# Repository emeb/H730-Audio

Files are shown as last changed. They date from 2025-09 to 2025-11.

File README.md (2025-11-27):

# H730-Audio

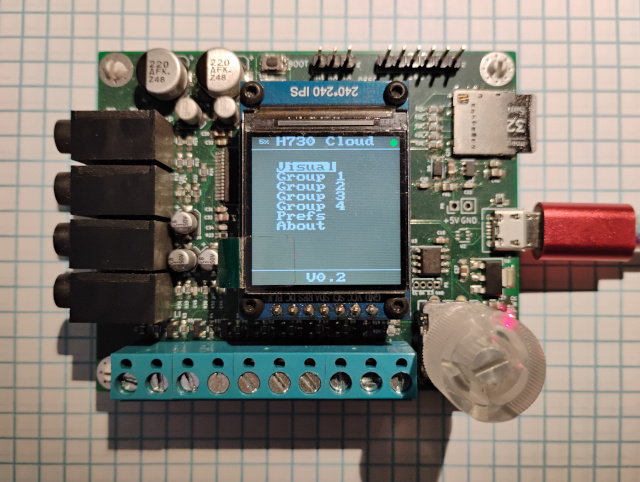
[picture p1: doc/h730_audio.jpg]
A small audio DSP board with GPIO, GUI and SD card.

## Abstract

A few years ago I was approached by my friend and colleague [Robert Rich](https://robertrich.com/) to help with a fascinating audio project that would be used to create immersive audio installations. He needed a device that would process sound in different ways - sometimes responding to sound, sometimes responding to environmental conditions. We kicked the ideas around for a while and tried various off-the-shelf solutions (Raspberry Pi, etc) but nothing was quite right so I ended up designing the H730 Audio board from scratch specifically for his requirements. The board needed audio input and output, storage, on-site configurability and the ability to use light sensors and this is what we ended up with:

- STM32H730 microcontroller - this is a compact, inexpensive and powerful device with plenty of I/O and on-chip resources that make for a capable "blank slate" on which to implement any DSP we might come up with

- WM8731 codec - I had a good stock of these in my inventory and I was very familiar with it. The device is EOL now and difficult to get, but in 2020 it was still a viable option. Today I'd probably use something like the Nuvoton NAU88C22 for equivalent features and performance.

- Micro SD-card slot - this is for storing long audio files of ambient recording and playback.

- 8 channel voltage-protected GPIO on a terminal block - for connecting sensors in environmental response installations. Specifically we used surplus solar panels to detect light changes throughout the day in order to modulate audio pitch and timbre.

- Micro USB - primarily used for 5V power, but also for USB DFU software updates.

- 240x240 IPS LCD - for user interface.

- Rotary encoder with pushbutton - for user interface.

- Quad SPI footprint for PSRAM or Flash memory - for audio sample storage or delay memory.

- 32kB I2C EEPROM - for user setting storage.

- Miscellaneous I/O headers for debug/development and "future expansion"

## Hardware

The design was created in an older version of Kicad and five boards were hand assembled - four went to Robert and several have been used in museum installations along with supporting hardware hand-built by Robert. The remaining board is in my collection. Design materials can be found in the [Hardware](./Hardware) directory.

## Firmware

Applications for this board were created in C using the STM32 HAL and ARM CMSIS libraries. Two audio installations are supported - a light-sensitive cloud generator and a day-long audio environment delay/feedback system. The source code for these applications is not provided at this time as they are proprietary, but basic hardware drivers are available in the [Firmware](./Firmware) directory.

## Documentation

The full users guide for the board with info on the I/O ports and use of the audio applications is here: [User Guide](./doc/h730_audio_info.pdf)

The board schematic is here: [Schematic](./doc/h730_audio_sch.pdf)

## Going Further

 Robert has a nice write-up on the system this board was used in over on his site that includes photos and videos:

[Sound Sculpture](https://robertrich.com/graphic-art/sound-sculpture/)

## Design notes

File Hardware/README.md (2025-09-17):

## H730 Audio - Hardware

This directory contains the Kicad 9.x design data for the H730 Audio board.
Note this was originally created in an earlier version of Kicad and although
was functional and correct in that environment, it has been automatically
upgraded to 9.x so there may be errors. Please use caution, run all applicable
DRC checks, etc before attempting to fab this design.

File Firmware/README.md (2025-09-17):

## H730 Firmware

This directory contains the firmware source code for the H730 Audio board, including the STM32 HAL and ARM CMSIS libraries that were used to build it. There is source code for basic functionality but the cloud and delay applications are withheld at this time.

The two applications are:

- blinky - basic initial test of the blinking LED on the board.

- main - a boilerplate / template for creating other applications that intializes all the on-board resources and creates a basic audio I/O stream.

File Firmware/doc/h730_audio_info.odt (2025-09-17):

H730 Audio Instructions

V0.3 – March 24, 2021

How to use this crazy thing

# What is it?

The H730 Audio board is a general purpose audio / DSP development system with the following features:

- STM32H730 MCU
  - 550MHz ARM Cortex M7 CPU
  - 128kB flash memory
  - 564kB SRAM
  - Range of peripherals – USB, SD, SPI, I2C, I2S, ADC, PDM, etc.
- WM8731 Stereo Audio Codec
  - 48/96 kSPS
  - 16 / 24 bit
  - Line level In / Out
  - Headphone Out
  - Mic In
- 240x240 0.96” IPS LCD display
- Rotary Encoder w/ pushbutton
- 8MB QSPI PSRAM (up to 43s delays for audio)
- 32kB I2C EEPROM for user settings
- Micro USB jack for power and firmware updates
- SD Card slot w/ power control
- 8-channel GPIO terminal block (for ADC, DAC or digital I/O)
  - Note that voltages between 0V to +3.3V are supported. There is some protection circuitry to guard against values outside this range, but it’s best to ensure these boundaries are not exceeded.
- Power & Status LEDs
- Reset and Bootloader buttons

# Tour

Boot & Reset buttons

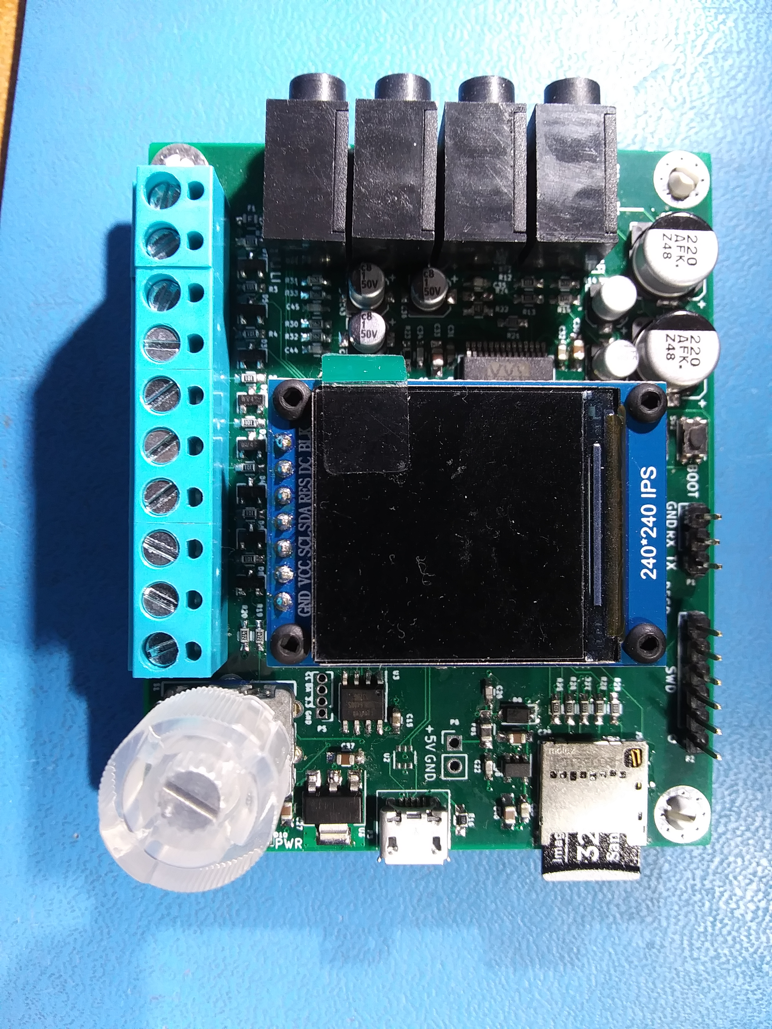
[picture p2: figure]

Principle I/O of the H730 Audio board

Headphone

Line Out

Mic In

Line In

USB

3.3V

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
Encoder + Button

Power LED (red)

Status LED (green)

SD Card

Program

Header

The photo above shows the location of jacks and controls on the H730 board. Some of these labels can also be found in the silkscreen on the back of the board.

# Setup

- Hook up 3.5mm stereo audio in / out cables
  - Choose either Line In/Out or Headphone / Mic. Line / Headphone outputs are always active, but Line / Mic inputs are only active for algorithms that require input.
  - Headphone output volume can be adjusted. Line output is not adjustable.
  - Line Input gain is adjustable. Mic input gain is only adjustable at two settings (0dB / 20dB)
  - Mic input is not stereo. Instead, the tip is the audio signal, ring is bias and shield is ground. This is compatible with standard PC microphones and headsets.
- Hook up control voltages to the terminal block as required.
  - Not all algorithms will use control voltages.
  - Use the +3.3V and GND terminals as required.
  - Note that the +3.3V terminal is provided with a self-resetting thermal fuse, but try to avoid shorting it to GND.
- Apply 5V power via the USB jack
- Observe the LCD for the title of the algorithm
- Note the Status (green) LED flashing at 1Hz
- Use the Encoder and button to select menu items and edit values to configure the application

# Firmware Updates

Firmware for the H730 Audio board can be loaded either via the 6-pin SWD header using an ST-Link adapter, or via the USB jack and the built-in USB DFU class bootloader. To use the USB DFU you will be provided with a .dfu file that the bootloader can accept. Follow these steps:

1. Connect the H730 Audio with a USB cable to a host computer which can run the dfu-util application (usually a Raspberry Pi or other Linux-based system.)
2. Press the BOOT button and hold it. It may be easier to do this with a blunt tool, like a pen.
3. Press and release the RST button. The green status LED should NOT be flashing after this point.
4. Release the BOOT button.
5. Run the dfu-util program with the proper command parameters on the host computer. Typically something like: dfu-util -a 0 -s 0x8000000 -D <firmware filename>
6. The dfu-util program will provide progress reports and should complete after about a minute, reporting success with the line “File downloaded successfully”, after which you may press RST again (without simultaneously pressing BOOT) to resume normal operation.

# Applications

There are currently two different end-use applications in development for the H730 Audio board:

## Cloud Generator

This is a cloud generator in the same class as the Synthtech E340, E352 or E370. It supports 4 voices or “groups” of up to 16 oscillators with independent frequency, amplitude, spread, chaos, waveform and stereo panning. Frequency and amplitude can be controlled by control voltages applied to the ADC inputs on the terminal block.

### Menu

Use the Encoder knob to navigate the 2-level menu. At power up the menu will be in the top page. Turn the knob to select a sub-page and press the knob to enter. Within sub-pages use the encoder to select editable items or to exit back to the top page.

The menu consists of

- Top – the main navigation page from which all other pages are chosen
  - Visual – a real-time graphic display of the frequency, amplitude and spread of the oscillator groups. Frequency is marked across the bottom of the graph and ranges from about 10Hz to over 10kHz. Amplitude ranges from 0dBfs at the top down to -64dBfs at the bottom. Amplitudes less than -64dBfs will still display a tiny nub near the bottom. Each cloud group is rendered in a different color and a color legend is shown above the graph.
  - Group 1-4 – the setup pages from which the parameters of each group are controlled
    - Frequency – the base frequency of the group ranges from ~8Hz to ~13kHz in equally tempered steps.
    - Frequency Scale – the sensitivity of the frequency to the CV input. Ranges +/-99% in 2% steps. A value of 0% means that the frequency is not affected by the CV.
    - Amplitude – the base amplitude of the group ranges fro 0dBfs to -99dBfs. A value of 0dBfs is loudest.
    - Amplitude Scale - the sensitivity of the amplitude to the CV input. Ranges +/-99% in 2% steps. A value of 0% means that the amplitude is not affected by the CV.
    - Spread - the bandwidth of the cloud. All the oscillators in the group will be evenly spread out across this range.
    - Kaos – the amount and rate of random frequency variation applied to each oscillator in the group.
    - Nosc – number of oscillators in the group. Ranges from 0 to 16 (0 disables the group).
    - Wave – the waveform for the oscillators. Can be Sine, Saw, Pulse. Note that the Saw and Pulse waves are not “bandlimited” and can alias noticeably at high frequencies.
    - Pan – the distribution of the group across the Left / Right stereo channels.
  - Prefs – sets some global parameters of the Cloud Generator
    - HPF – corner frequency of a 2nd-order HPF on the combined output.
    - LPF – corner frequency of a 2nd-order LPF on the combined output.
    - HPVol – volume control for the headphone output.
    - Pull – selects the type of pull resistor to engage on the CV inputs. Options are:
      - Off – no pull resistor.
      - Down – a pull to ground is enabled. This is a good choice for solar cells that are referenced to the GND input terminal.
      - Up – a pull to 3.3V is enabled this may be useful for some situations.
  - About – displays some pertinent info about the running application, including
    - Time, Date and Version of the firmware build
    - Current status of the 8 CV inputs
    - USB Bus voltage – usually between 4.5-5.0V
    - Reference voltage – should be 3.3V always.
    - Temp – the STM32H730 die temperature. Usually around 50C.

At the top of each menu page is a header with the name of the page, the current CPU load and the EEPROM status indicator which is green when the EEPROM is up-to-date and turns red for a few seconds when the EEPROM is about to be updated due to a parameter change.

### Terminal

The 8 CV inputs on the terminal block are allocated thus:

- PA0 – Frequency for Group 1
- PA1 – Amplitude for Group 1
- PA2 – Frequency for Group 2
- PA3 – Amplitude for Group 2
- PA4 – Frequency for Group 3
- PA5 – Amplitude for Group 3
- PA6 – Frequency for Group 4
- PA7 – Amplitude for Group 4

## Delay

The Delay application is a simple 48ksps stereo audio delay line that provides delay times in excess of 24 hours using a non-volatile SD card as the buffer. Audio data is stored on the SD card in eight WAV files, so the previous 24 hours of recorded audio can be captured and used offline – the files can be pasted together without glitches at the splices for extended recordings.

### Menu

Use the Encoder knob to navigate the 2-level menu. At power up the menu will be in the top page. Turn the knob to select a sub-page and press the knob to enter. Within sub-pages use the encoder to select editable items or to exit back to the top page.

The menu consists of

- Top – the main navigation page from which all other pages are chosen
  - Delay – the main control page for the Delay.
    - There are five editable parameters:
      - Delay, arranged in three items on one line:
        - HH – the number of hours in the total amount of delay
        - MM – the number of minutes in the total amount of delay
        - SS – the number of seconds in the total amount of delay
      - Mix – Dry/Wet mix amount, where 0% is full dry (undelayed) and 100% is full wet (delayed) signal.
      - Fbk – feedback amount, where 0% is no feedback and 100% is full feedback with no attenuation.
    - There are a number of status displays
      - Level meters – audio signal level meters for left & right input & output are displayed as colored bar-graphs. Best operation is obtained with signal levels in the green or yellow regions. When signal levels are in the red region then clipping is likely to occur.
      - dly – the total amount of delay, displayed in HH:MM:SS format. Regardless of the user settings this value will not exceed the maximum allowed by the active delay buffer – either 43 seconds for the QSPI RAM or 24:51:18 for the SD card.
      - wpt – the current location of the write pointer (same as the record head) in the delay buffer, displayed in HH:MM:SS format.
      - rpt – the current location of the read pointer (same as playback head) in the delay buffer, displayed in HH:MM:SS format.
      - len – the total length of the buffer, displayed in HH:MM:SS format. For a properly formatted SD card this should read 24:51:18, but if the SD card is not present or isn’t correctly formatted then it will read 00:00:43 for the duration of the on-board QSPI RAM.
      - File – the current file and percentage of the write pointer. This is just a different way of looking at the “wpt” value above and can help to understand where the wrap-around point in the buffer is when using the recorded data externally.
  - Prefs – sets some global parameters of the Delay
    - HPF – corner frequency of a 2nd-order HPF on the combined output.
    - LPF – corner frequency of a 2nd-order LPF on the combined output.
    - HPVl – volume control for the headphone output.
    - Inpt – input source, either Line or Mic
    - InVl – input volume control for the line input.
    - Mbst – mic boost, either 0dB or 20dB.
    - Pull – selects the type of pull resistor to engage on the CV inputs. Options are:
      - Off – no pull resistor.
      - Down – a pull to ground is enabled. This is a good choice for solar cells that are referenced to the GND input terminal.
      - Up – a pull to 3.3V is enabled this may be useful for some situations.
    - Lmtr – a limiter on the input signal level which can prevent external feedback from causing the signal to become too strong. There are three levels available:
      - Soft (default) - -3dBfs threshold and slow response.
      - Med - -6dBfs threshold and medium response.
      - Fast - -12dBfs response and fast response.
      - Off – limiter disabled.
  - About – displays some pertinent info about the running application, including
    - Time, Date and Version of the firmware build
    - Current status of the 8 CV inputs
    - USB Bus voltage – usually between 4.5-5.0V
    - Reference voltage – should be 3.3V always.
    - Temp – the STM32H730 die temperature. Usually around 50C.

At the top of each menu page is a header with the name of the page, the current CPU load, the type of memory in use (either a red “Q” for the on-board QSPI RAM or a green “S” for the SD card) and the EEPROM status indicator which is green when the EEPROM is up-to-date and turns red for a few seconds when the EEPROM is about to be updated due to a parameter change.

### Operation

When first powered on the Delay firmware will check to see if there is an SD card present which has been properly set up to use as a delay buffer. During this step a text box that says “Checking Files” will be displayed for 2 – 20 seconds depending on what it discovers. The process flows like this:

- Check if there is an SD card present
  - If no SD card is found then the on-board QSPI RAM is used for the delay buffer. This is only 8MB in size so the maximum delay available is 43 seconds.
- If an SD card is present, check to see if the card is large enough.
  - If the card is not large enough a warning “SD card too small” will be displayed and the QSPI RAM will be used. Try again with a card of 32GB in size.
- If the card is large enough, check to see that the eight 2.1GB WAV files have already been set up.
  - If the files are present they are put into use.
  - If the files are not present then the software attempts to create them. Creating the files requires a lot of operations on the SD card and can take several seconds per file.
    - Note that if the card has previously been used for other purposes it may not be possible to create the files. If this happens then a warning “File Error” will be displayed and it will be necessary to remove the card and reformat it to provide a clean filesystem.
- After all the files have be either found or created then the Delay firmware will proceed to the Top menu.

At power up the Delay begins writing into the audio buffer memory at the beginning and will not start playing back until the read pointer enters a region of the buffer with known-good audio. Since the firmware doesn’t have any way to know if the SD card files contain previously recorded sounds there will always be a period of silence that lasts for the duration of the chosen delay.

### Files

Buffered Audio data is stored in eight 2.1GB 16-bit stereo WAV files named “AUDIO0.WAV” – “AUDIO7.WAV”. To use the recorded audio data simply power down the board, remove the SD card and connect it to a PC or Mac with an SD card reader.

These files should only be copied or read from the SD card. Under no circumstances should you attempt to create or overwrite these files on a PC or Mac as this disturbs the special formatting. If the files are accidentally disturbed then it’s best to reformat the card to wipe it clean and let the Delay firmware recreate the files from scratch.

The format of these files should be compatible with well-designed audio production and playback software, but there are some unique characteristics of the WAV header that are necessary for the firmware to access the SD card quickly, so it is possible that some software may have difficulty reading these files. The WAV files have been used successfully with the following software:

- Audacity
- SOX
- VLC

If you experience difficulties with reading the WAV files, try importing and exporting the files with a known-good application such as those listed above.

### Terminal

The Delay firmware does not use any of the analog input connections. Port pins 4, 6 and 7 are used for some diagnostic outputs but these are not useful in normal operation.

### Power

In order to prevent corrupting the SD card, the Delay firmware has been designed to detect when 5V power is removed and quickly enter a “safe” mode during which all firmware activity is disabled and the green LED will flash at ~10Hz. Because of this, it is very sensitive to low voltage or poorly regulated supplies. If you plug the USB power supply in and the red power LED lights up and the green LED flashes at a fast rate but the display does not light, or the firmware appears to lock up then it is possible that the supply voltage is too low. Please ensure that you use a supply with at least 5V @ 1A rating.

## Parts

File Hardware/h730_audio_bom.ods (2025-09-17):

refdes | value | footprint | qty | Disty | Reference | Price ea | Price total
C2, C3 | 33pf | Capacitors_SMD:C_0603_HandSoldering | 2 | digikey | https://www.digikey.com/en/products/detail/tdk-corporation/C1608C0G1H330J080AA/513765 | 0.0367 | 0.0734
C5, C16, C20, C24, C27-C30, C33, C37, C40, C41 | 10uf | Capacitors_SMD:C_0805_HandSoldering | 12 | digikey | https://www.digikey.com/en/products/detail/samsung-electro-mechanics/CL21B106KOQNNNG/5958100 | 0.1176 | 1.4112
C9, C12 | 2.2uf | Capacitors_SMD:C_0805_HandSoldering | 2 | digikey | https://www.digikey.com/en/products/detail/tdk-corporation/C2012X7R1E225K125AB/2619201 | 0.302 | 0.604
C13, C14 | 220uF | Capacitors_SMD:CP_Elec_8x10.5 | 2 | digikey | https://www.digikey.com/en/products/detail/cornell-dubilier-electronics-cde/AVE227M10E16T-F/2096319 | 0.353 | 0.706
C17, C18 | 10uF | Capacitors_SMD:CP_Elec_4x5.3 | 2 | mouser | https://www.mouser.com/ProductDetail/598-AVE106M10B12T-F | 0.366 | 0.732
C22, C26, C34, C35, C44, C45 | 220pf | Capacitors_SMD:C_0603_HandSoldering | 6 | digikey | https://www.digikey.com/en/products/detail/yageo/CC0603KRNPO9BN221/8025120 | 0.038 | 0.228
C36, C42, C43 | 1uF | Capacitors_SMD:CP_Elec_4x5.3 | 3 | mouser | https://www.mouser.com/ProductDetail/598-AVE105M50B12T-F | 0.144 | 0.432
C1, C4, C6-C8, C10, C11, C15, C19, C21, C23, C25, C31, C32, C38, C39 | 0.1uf | Capacitors_SMD:C_0603_HandSoldering | 16 | mouser | https://www.mouser.com/ProductDetail/80-C0603C104K5R | 0.025 | 0.4
D1-D8 | BAT54S | Package_TO_SOT_SMD:SOT-23 | 8 | digikey | https://www.digikey.com/en/products/detail/diodes-incorporated/BAT54S-7-F/755493 | 0.132 | 1.056
D9 | D_Schottky | footprints:D_SOD-123W | 1 | mouser | https://www.mouser.com/ProductDetail/621-1N5819HW-F | 0.262 | 0.262
D10, D11 | LED | LEDs:LED_0603 | 2 | mouser | https://www.mouser.com/ProductDetail/720-LGL29KF2J124Z | 0.119 | 0.238
DIS1 | IPS_LCD | footprints:IPS_LCD | 1 | aliexpress | https://www.aliexpress.com/item/32867668144.html | 3.28 | 3.28
F1 | Polyfuse 0603L035YR | Resistors_SMD:R_0603_HandSoldering | 1 | digikey | https://www.digikey.com/en/products/detail/littelfuse-inc/0603L035YR/1920207 | 0.87 | 0.87
FB1 | Ferrite_Bead | Resistors_SMD:R_0805_HandSoldering | 1 | mouser | https://www.mouser.com/ProductDetail/81-BLM21P331SG | 0.06 | 0.06
J1 | Screw_Terminal_01x10 | footprints:screw_terminal_10 | 1 | digikey | https://www.digikey.com/en/products/detail/cui-devices/TB001-500-10BE/10064066 | 1.44 | 1.44
J2-J4, J6 | STEREO_JACK | footprints:CUI_SJ1-3535NG-GR | 4 | digikey | https://www.digikey.com/en/products/detail/cui-devices/SJ1-3533NG/738701 | 1.025 | 4.1
J5 | Micro_SD_Card_Det | footprints:micro_sd_molex_1040310-811 | 1 | digikey | https://www.digikey.com/en/products/detail/molex/1040310811/2804769 | 1.83 | 1.83
L1 | Ferrite Bead 2.5k | Resistors_SMD:R_0603_HandSoldering | 1 | digikey | https://www.digikey.com/en/products/detail/murata-electronics/BLM18BD252SN1D/584239 | 0.0428 | 0.0428
P1 | CONN_01X03 | Pin_Headers:Pin_Header_Straight_1x03_Pitch2.54mm | 1 | misc |  | 0 | 0
P2 | CONN_01X06 | Pin_Headers:Pin_Header_Straight_1x06_Pitch2.54mm | 1 | misc |  | 0 | 0
P3 | USB_OTG | Connect:USB_Micro-B_10103594-0001LF | 1 | digikey | https://www.digikey.com/en/products/detail/amphenol-icc-fci/10103594-0001LF/2350357 | 0.766 | 0.766
R10, R11, R14, R15 | 47k | Resistors_SMD:R_0603_HandSoldering | 4 | digikey | https://www.digikey.com/en/products/detail/panasonic-electronic-components/ERJ-3GEYJ473V/135787 | 0.0182 | 0.0728
R2-R9, R12, R13 | 100 | Resistors_SMD:R_0603_HandSoldering | 10 | digikey |  | 0.0182 | 0.182
R16 | 1M | Resistors_SMD:R_0603_HandSoldering | 1 | digikey |  | 0.0182 | 0.0182
R1, R17-R20 | 4.7k | Resistors_SMD:R_0603_HandSoldering | 5 | digikey |  | 0.0182 | 0.091
R22 | 680 | Resistors_SMD:R_0603_HandSoldering | 1 | digikey |  | 0.0182 | 0.0182
R23 | 56 | Resistors_SMD:R_0603_HandSoldering | 1 | digikey |  | 0.0182 | 0.0182
R21, R24-R29 | 10k | Resistors_SMD:R_0603_HandSoldering | 7 | digikey |  | 0.0182 | 0.1274
R30-R33 | 5.6k | Resistors_SMD:R_0603_HandSoldering | 4 | digikey |  | 0.0182 | 0.0728
R34, R35 | 1k | Resistors_SMD:R_0603_HandSoldering | 2 | digikey |  | 0.0182 | 0.0364
S1 | encoder_en11 | footprints:ENC_11 | 1 | mouser | https://www.mouser.com/ProductDetail/858-EN11-VSM1AF20 | 1.13 | 1.13
SW1, SW2 | SW_PUSH | Buttons_Switches_SMD:SW_SPST_KMR2 | 2 | digikey | https://www.digikey.com/en/products/detail/c-k/KMR241NG-LFS/2176498 | 0.5428 | 1.0856
U1 | STM32H730VBTx | Package_QFP:LQFP-100_14x14mm_P0.5mm | 1 | digikey | https://www.digikey.com/en/products/detail/stmicroelectronics/STM32H730VBT6/13171210 | 6.74 | 6.74
U2 | IP4220CZ6 | Package_TO_SOT_SMD:SOT-363_SC-70-6 | 1 | digikey | https://www.digikey.com/en/products/detail/nexperia-usa-inc/IP4220CZ6,125/1133548 | 0.329 | 0.329
U3 | LY68L6400SLIT | Housings_SOIC:SOIC-8_3.9x4.9mm_Pitch1.27mm | 1 | LCSC | https://lcsc.com/product-detail/RAM_Lyontek-Inc-LY68L6400SLIT_C261881.html | 1.46 | 1.46
U4 | WM8731 | Housings_SSOP:SSOP-28_5.3x10.2mm_Pitch0.65mm | 1 | mouser | https://www.mouser.com/ProductDetail/238-WM8731SEDS-V | 4.15 | 4.15
U5 | 24LC256 | Housings_SOIC:SOIC-8_3.9x4.9mm_Pitch1.27mm | 1 | digikey | https://www.digikey.com/en/products/detail/microchip-technology/24LC256T-I-SN/443546 | 0.8 | 0.8
U6 | LD1117S33TR_SOT223 | Package_TO_SOT_SMD:SOT-223-3_TabPin2 | 1 | mouser | https://www.mouser.com/ProductDetail/511-LD1117S33C | 0.341 | 0.341
U7 | LP2985-3.3 | Package_TO_SOT_SMD:SOT-23-5 | 1 | mouser | https://www.mouser.com/ProductDetail/595-LP2985-33DBVR | 0.399 | 0.399
U8 | MCP1802x-xx02xOT | Package_TO_SOT_SMD:SOT-23-5 | 1 | digikey | https://www.digikey.com/en/products/detail/microchip-technology/MCP1802T-3302I-OT/1679144 | 0.56 | 0.56
Y1 | 8MHz | Crystals:Crystal_SMD_Abracon_ABM3-2pin_5.0x3.2mm_HandSoldering | 1 | digikey | https://www.digikey.com/en/products/detail/txc-corporation/7A-8-000MAAJ-T/2626964 | 0.65 | 0.65
PCB |  |  | 1 | JLCPCB |  | 4.36 | 4.36
Brass Spacer | 970120244 |  | 4 | digikey | https://www.digikey.com/en/products/detail/w-rth-elektronik/970120244/9488556 | 0.627 | 2.508
M2 Screw |  |  | 8 | misc |  | 0 | 0
Knob | COM-10597 |  | 1 | digikey | https://www.digikey.com/en/products/detail/sparkfun-electronics/COM-10597/7229845 | 0.95 | 0.95
Nylon Spacer | 9019 |  | 4 | digikey | https://www.digikey.com/en/products/detail/keystone-electronics/9019/2746024 | 0.2044 | 0.8176
 |  |  |  |  |  | Total | 45.4486

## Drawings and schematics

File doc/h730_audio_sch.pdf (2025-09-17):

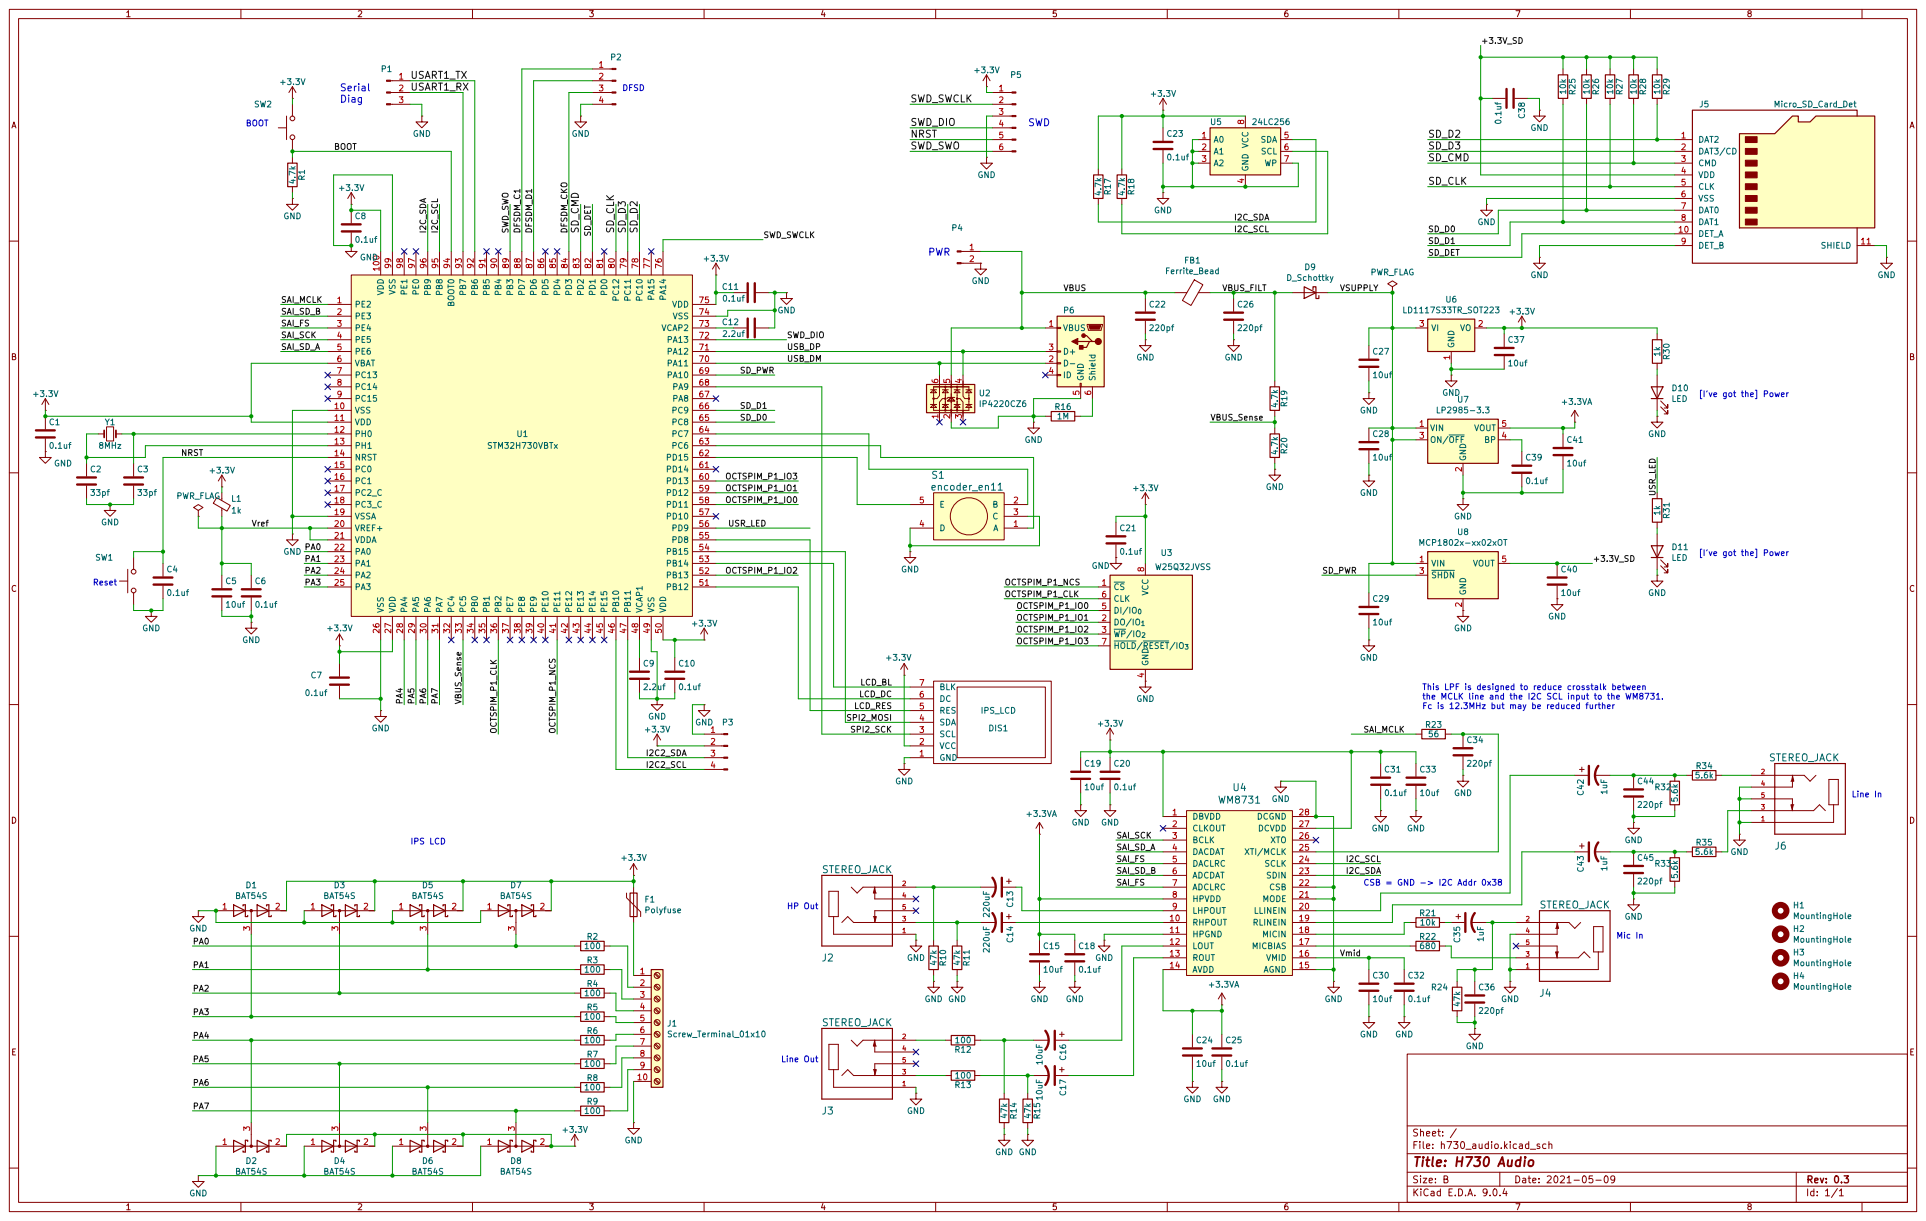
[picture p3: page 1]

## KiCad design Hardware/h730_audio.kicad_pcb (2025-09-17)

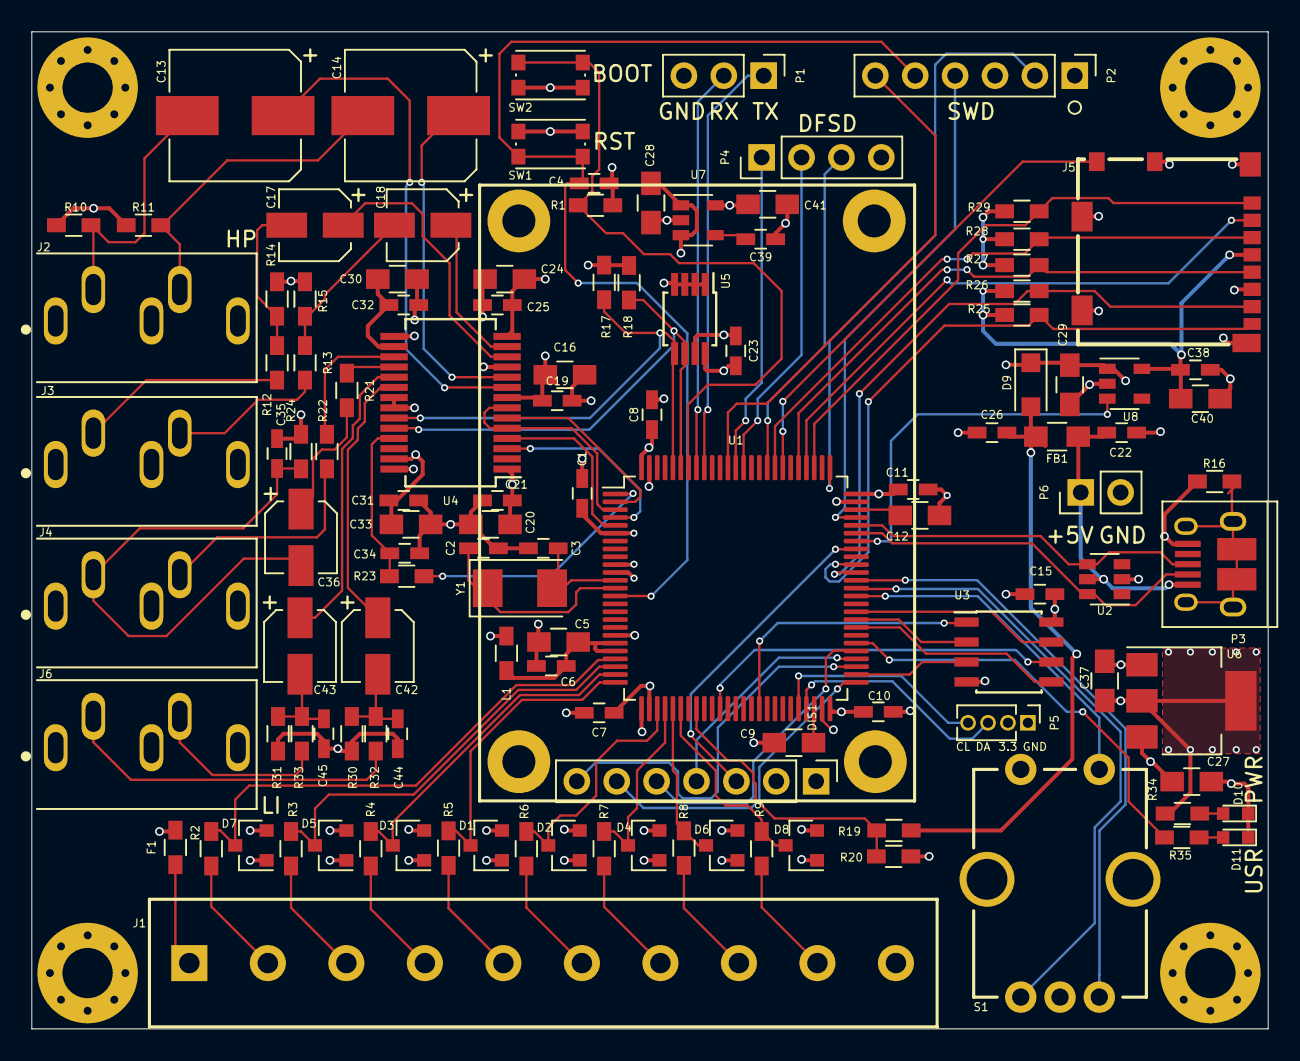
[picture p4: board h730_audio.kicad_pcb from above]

Board: 4 copper layers, 78.7 x 63.5 mm, 123 parts (0 on the bottom side), 101 nets.

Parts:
C1, C4, C6, C7, C8, C10, C11, C15, C19, C21, C23, C25, C31, C32, C38, C39: 0.1uf; C_0603_HandSoldering
C2, C3: 33pf; C_0603_HandSoldering
C5, C16, C20, C24, C27, C28, C29, C30, C33, C37, C40, C41: 10uf; C_0805_HandSoldering
C9, C12: 2.2uf; C_0805_HandSoldering
C13, C14: 220uF; CP_Elec_8x10.5
C17, C18: 10uF; CP_Elec_4x5.3
C22, C26, C34, C35, C44, C45: 220pf; C_0603_HandSoldering
C36, C42, C43: 1uF; CP_Elec_4x5.3
D1, D2, D3, D4, D5, D6, D7, D8: BAT54S; SOT-23
D9: D_Schottky; D_SOD-123W
D10, D11: LED; LED_0603
DIS1: IPS_LCD
F1: Polyfuse; R_0603_HandSoldering
FB1: Ferrite_Bead; R_0805_HandSoldering
H1, H2, H3, H4: MountingHole; MountingHole_3.2mm_M3_Pad_Via
J1: Screw_Terminal_01x10; screw_terminal_10
J2, J3, J4, J6: STEREO_JACK; CUI_SJ1-3535NG-GR
J5: Micro_SD_Card_Det; micro_sd_molex_1040310-811
L1: 1k; R_0603_HandSoldering
P1: CONN_01X03; Pin_Header_Straight_1x03_Pitch2.54mm
P2: CONN_01X06; Pin_Header_Straight_1x06_Pitch2.54mm
P3: USB_OTG; USB_Micro-B_10103594-0001LF
P4: CONN_01X03; Pin_Header_Straight_1x04_Pitch2.54mm
P5: CONN_01X04; Pin_Header_Straight_1x04_Pitch1.27mm
P6: CONN_01X03; Pin_Header_Straight_1x02_Pitch2.54mm
R1, R17, R18, R19, R20: 4.7k; R_0603_HandSoldering
R2, R3, R4, R5, R6, R7, R8, R9, R12, R13: 100; R_0603_HandSoldering
R10, R11, R14, R15, R24: 47k; R_0603_HandSoldering
R16: 1M; R_0603_HandSoldering
R21, R25, R26, R27, R28, R29: 10k; R_0603_HandSoldering
R22: 680; R_0603_HandSoldering
R23: 56; R_0603_HandSoldering
R30, R31, R32, R33: 5.6k; R_0603_HandSoldering
R34, R35: 1k; R_0603_HandSoldering
S1: encoder_en11; ENC_11
SW1, SW2: SW_PUSH; SW_SPST_KMR2
U1: STM32H730VBTx; LQFP-100_14x14mm_P0.5mm
U2: IP4220CZ6; SOT-23-6
U3: W25Q32JVSS; SOIC-8_3.9x4.9mm_Pitch1.27mm
U4: WM8731; SSOP-28_5.3x10.2mm_Pitch0.65mm
U5: 24LC256; MSOP-8_3x3mm_Pitch0.65mm
U6: LD1117S33TR_SOT223; SOT-223-3_TabPin2
U7: LP2985-3.3; SOT-23-5
U8: MCP1802x-xx02xOT; SOT-23-5
Y1: 8MHz; Crystal_SMD_Abracon_ABM3-2pin_5.0x3.2mm

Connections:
+3.3VA: C16.1, C19.1, C24.1, C25.1, C41.1, U4.8, U4.14, U7.5
+3V3: C1.1, C7.1, C8.1, C10.1, C11.1, C15.1, C20.1, C21.1, C23.1, C31.1, C33.1, C37.1, D1.2, D2.2, D3.2, D4.2, D5.2, D6.2, D7.2, D8.2, DIS1.2, F1.1, L1.1, P2.1, P5.2, R17.1, R18.1, R34.1, SW2.2, U1.6, U1.11, U1.27, U1.50, U1.75, U1.100, U3.8, U4.1, U4.27, U5.8, U6.2
/+3.3V_SD: C38.2, C40.1, J5.4, R25.1, R26.1, R27.1, R28.1, R29.1, U8.5
/BOOT: R1.1, SW2.1, U1.94
/DFSDM_C1: P4.1, U1.88
/DFSDM_CKO: P4.3, U1.84
/DFSDM_D1: P4.2, U1.87
/I2C2_SCL: P5.4, U1.46
/I2C2_SDA: P5.3, U1.47
/I2C_SCL: R18.2, U1.95, U4.24, U5.6
/I2C_SDA: R17.2, U1.96, U4.23, U5.5
/LCD_BL: DIS1.7, U1.53
/LCD_DC: DIS1.6, U1.51
/LCD_RES: DIS1.5, U1.55
/NRST: C4.1, P2.5, SW1.2, U1.14
/OCTSPIM_P1_CLK: U1.36, U3.6
/OCTSPIM_P1_IO0: U1.58, U3.5
/OCTSPIM_P1_IO1: U1.59, U3.2
/OCTSPIM_P1_IO2: U1.52, U3.3
/OCTSPIM_P1_IO3: U1.60, U3.7
/OCTSPIM_P1_NCS: U1.41, U3.1
/PA0: D7.3, R2.1, U1.22
/PA1: D5.3, R3.1, U1.23
/PA2: D3.3, R4.1, U1.24
/PA3: D1.3, R5.1, U1.25
/PA4: D2.3, R6.1, U1.28
/PA5: D4.3, R7.1, U1.29
/PA6: D6.3, R8.1, U1.30
/PA7: D8.3, R9.1, U1.31
/SAI_FS: U1.3, U4.5, U4.7
/SAI_MCLK: R23.1, U1.1
/SAI_SCK: U1.4, U4.3
/SAI_SD_A: U1.5, U4.4
/SAI_SD_B: U1.2, U4.6
/SD_CLK: J5.5, R27.2, U1.80
/SD_CMD: J5.3, R28.2, U1.83
/SD_D0: J5.7, R26.2, U1.65
/SD_D1: J5.8, R25.2, U1.66
/SD_D2: J5.1, R29.2, U1.78
/SD_D3: J5.2, U1.79
/SD_DET: J5.10, U1.82
/SD_PWR: U1.69, U8.3
/SPI2_MOSI: DIS1.4, U1.54
/SPI2_SCK: DIS1.3, U1.68
/SWD_DIO: P2.4, U1.72
/SWD_SWCLK: P2.2, U1.76
/SWD_SWO: P2.6, U1.89
/USART1_RX: P1.2, U1.93
/USART1_TX: P1.1, U1.92
/USB_DM: P3.2, U1.70, U2.6
/USB_DP: P3.3, U1.71, U2.4
/USR_LED: R35.1, U1.56
/VBUS: C22.1, FB1.2, P3.1, P6.1, U2.5
/VBUS_FILT: C26.1, D9.2, FB1.1, R19.1
/VBUS_Sense: R19.2, R20.1, U1.33
/VSUPPLY: C27.1, C28.1, C29.1, D9.1, U6.3, U7.1, U7.3, U8.1
/Vmid: C30.1, C32.1, U4.16
/Vref: C5.1, C6.1, L1.2, U1.20, U1.21
GND: C1.2, C2.2, C3.2, C4.2, C5.2, C6.2, C7.2, C8.2, C9.2, C10.2, C11.2, C12.2, C15.2, C16.2, C19.2, C20.2, C21.2, C22.2, C23.2, C24.2, C25.2, C26.2, C27.2, C28.2, C29.2, C30.2, C31.2, C32.2, C33.2, C34.2, C35.2, C37.2, C38.1, C39.2, C40.2, C41.2, C44.2, C45.2, D1.1, D2.1, D3.1, D4.1, D5.1, D6.1, D7.1, D8.1, D10.1, D11.1, DIS1.1, J1.10, J2.1, J3.1, J4.1, J4.4, J5.6, J5.9, J5.11, J6.1, J6.4, J6.5, P1.3, P2.3, P3.5, P4.4, P5.1, P6.2, R1.2, R10.2, R11.2, R14.2, R15.2, R16.1, R20.2, R24.1, R30.1, R31.1, S1.3, S1.4, SW1.1, U1.10, U1.19, U1.26, U1.49, U1.74, U1.99, U2.2, U3.4, U4.11, U4.15, U4.21, U4.22, U4.28, U5.1, U5.2, U5.3, U5.4, U5.7, U6.1, U7.2, U8.2
unnamed: C2.1, U1.13, Y1.1
unnamed: C3.1, U1.12, Y1.2
unnamed: C9.1, U1.48
unnamed: C12.1, U1.73
unnamed: C13.1, U4.9
unnamed: C13.2, J2.2, R10.1
unnamed: C14.1, U4.10
unnamed: C14.2, J2.3, R11.1
unnamed: C17.1, U4.12
unnamed: C17.2, R12.1, R14.1
unnamed: C18.1, U4.13
unnamed: C18.2, R13.1, R15.1
unnamed: C34.1, R23.2, U4.25
unnamed: C35.1, C36.2, J4.2, R24.2
unnamed: C36.1, R21.2
unnamed: C39.1, U7.4
unnamed: C42.1, U4.20
unnamed: C42.2, C44.1, R30.2, R32.1
unnamed: C43.1, U4.19
unnamed: C43.2, C45.1, R31.2, R33.1
unnamed: D10.2, R34.2
unnamed: D11.2, R35.2
unnamed: F1.2, J1.1
unnamed: J1.2, R2.2
unnamed: J1.3, R3.2
unnamed: J1.4, R4.2
unnamed: J1.5, R5.2
unnamed: J1.6, R6.2
unnamed: J1.7, R7.2
unnamed: J1.8, R8.2
unnamed: J1.9, R9.2
unnamed: J3.2, R12.2
unnamed: J3.3, R13.2
unnamed: J4.3, R22.2
unnamed: J6.2, R32.2
unnamed: J6.3, R33.2
unnamed: P3.6, R16.2
unnamed: R21.1, U4.18
unnamed: R22.1, U4.17
unnamed: S1.1, U1.63
unnamed: S1.2, U1.64
unnamed: S1.5, U1.62

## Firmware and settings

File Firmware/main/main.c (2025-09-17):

/*
 * main.c - H730 Audio
 * 12-04-20 E. Brombaugh
 ******************************************************************************
 * Changelog
 *
 * date: 2020-12-04 V0.0
 * Initial creation
 *
 */

#include "main.h"
#include "usart.h"
#include "printf.h"
#include "led.h"
#include "systick.h"
#include "st7789.h"
#include "gfx.h"
#include "adc.h"
#include "shared_i2c.h"
#include "eeprom.h"
#include "audio.h"
#include "codec.h"
#include "sai.h"
#include "cyclesleep.h"
#include "qspi.h"
#include "sdio.h"

/* build version in simple format */
const char *fwVersionStr = "V0.0";

/* build time */
const char *bdate = __DATE__;
const char *btime = __TIME__;

/**
* @brief  CPU L1-Cache enable.
* @param  None
* @retval None
*/
static void CPU_CACHE_Enable(void)
{
  /* Enable I-Cache */
  SCB_EnableICache();

  /* Enable D-Cache */
  SCB_EnableDCache();
}

/**
  * @brief  This function is executed in case of error occurrence.
  * @param  None
  * @retval None
  */
static void Error_Handler(void)
{
  while(1)
  {
  }
}

/**
  * @brief System Clock Configuration
  * @retval None
  */
void SystemClock_Config(void)
{
  RCC_OscInitTypeDef RCC_OscInitStruct = {0};
  RCC_ClkInitTypeDef RCC_ClkInitStruct = {0};
  RCC_PeriphCLKInitTypeDef PeriphClkInitStruct = {0};

  /** Supply configuration update enable
  */
  HAL_PWREx_ConfigSupply(PWR_LDO_SUPPLY);
  /** Configure the main internal regulator output voltage
  */
  __HAL_PWR_VOLTAGESCALING_CONFIG(PWR_REGULATOR_VOLTAGE_SCALE0);

  while(!__HAL_PWR_GET_FLAG(PWR_FLAG_VOSRDY)) {}
  /** Macro to configure the PLL clock source
  */
  __HAL_RCC_PLL_PLLSOURCE_CONFIG(RCC_PLLSOURCE_HSE);
  /** Initializes the RCC Oscillators according to the specified parameters
  * in the RCC_OscInitTypeDef structure.
  */
  RCC_OscInitStruct.OscillatorType = RCC_OSCILLATORTYPE_HSE;
  RCC_OscInitStruct.HSEState = RCC_HSE_ON;
  RCC_OscInitStruct.PLL.PLLState = RCC_PLL_ON;
  RCC_OscInitStruct.PLL.PLLSource = RCC_PLLSOURCE_HSE;
  RCC_OscInitStruct.PLL.PLLM = 4;
  RCC_OscInitStruct.PLL.PLLN = 275;
  RCC_OscInitStruct.PLL.PLLP = 1;
  RCC_OscInitStruct.PLL.PLLQ = 4;
  RCC_OscInitStruct.PLL.PLLR = 2;
  RCC_OscInitStruct.PLL.PLLRGE = RCC_PLL1VCIRANGE_1;
  RCC_OscInitStruct.PLL.PLLVCOSEL = RCC_PLL1VCOWIDE;
  RCC_OscInitStruct.PLL.PLLFRACN = 0;
  if (HAL_RCC_OscConfig(&RCC_OscInitStruct) != HAL_OK)
  {
    Error_Handler();
  }
  /** Initializes the CPU, AHB and APB buses clocks
  */
  RCC_ClkInitStruct.ClockType = RCC_CLOCKTYPE_HCLK|RCC_CLOCKTYPE_SYSCLK
                              |RCC_CLOCKTYPE_PCLK1|RCC_CLOCKTYPE_PCLK2
                              |RCC_CLOCKTYPE_D3PCLK1|RCC_CLOCKTYPE_D1PCLK1;
  RCC_ClkInitStruct.SYSCLKSource = RCC_SYSCLKSOURCE_PLLCLK;
  RCC_ClkInitStruct.SYSCLKDivider = RCC_SYSCLK_DIV1;
  RCC_ClkInitStruct.AHBCLKDivider = RCC_HCLK_DIV2;
  RCC_ClkInitStruct.APB3CLKDivider = RCC_APB3_DIV2;
  RCC_ClkInitStruct.APB1CLKDivider = RCC_APB1_DIV2;
  RCC_ClkInitStruct.APB2CLKDivider = RCC_APB2_DIV2;
  RCC_ClkInitStruct.APB4CLKDivider = RCC_APB4_DIV2;

  if (HAL_RCC_ClockConfig(&RCC_ClkInitStruct, FLASH_LATENCY_3) != HAL_OK)
  {
    Error_Handler();
  }
  PeriphClkInitStruct.PeriphClockSelection = RCC_PERIPHCLK_USART1|RCC_PERIPHCLK_DFSDM1
                              |RCC_PERIPHCLK_SPI2|RCC_PERIPHCLK_SAI1
                              |RCC_PERIPHCLK_SDMMC|RCC_PERIPHCLK_I2C2
                              |RCC_PERIPHCLK_ADC|RCC_PERIPHCLK_I2C1
                              |RCC_PERIPHCLK_USB|RCC_PERIPHCLK_OSPI;
  PeriphClkInitStruct.PLL2.PLL2M = 4;
  PeriphClkInitStruct.PLL2.PLL2N = 196;
  PeriphClkInitStruct.PLL2.PLL2P = 4;
  PeriphClkInitStruct.PLL2.PLL2Q = 2;
  PeriphClkInitStruct.PLL2.PLL2R = 2;
  PeriphClkInitStruct.PLL2.PLL2RGE = RCC_PLL2VCIRANGE_1;
  PeriphClkInitStruct.PLL2.PLL2VCOSEL = RCC_PLL2VCOWIDE;
  PeriphClkInitStruct.PLL2.PLL2FRACN = 4981;
  PeriphClkInitStruct.PLL3.PLL3M = 4;
  PeriphClkInitStruct.PLL3.PLL3N = 96;
  PeriphClkInitStruct.PLL3.PLL3P = 4;
  PeriphClkInitStruct.PLL3.PLL3Q = 4;
  PeriphClkInitStruct.PLL3.PLL3R = 2;
  PeriphClkInitStruct.PLL3.PLL3RGE = RCC_PLL3VCIRANGE_1;
  PeriphClkInitStruct.PLL3.PLL3VCOSEL = RCC_PLL3VCOWIDE;
  PeriphClkInitStruct.PLL3.PLL3FRACN = 0;
  PeriphClkInitStruct.OspiClockSelection = RCC_OSPICLKSOURCE_D1HCLK;
  PeriphClkInitStruct.SdmmcClockSelection = RCC_SDMMCCLKSOURCE_PLL;
  PeriphClkInitStruct.Sai1ClockSelection = RCC_SAI1CLKSOURCE_PLL2;
  PeriphClkInitStruct.Spi123ClockSelection = RCC_SPI123CLKSOURCE_PLL;
  PeriphClkInitStruct.Dfsdm1ClockSelection = RCC_DFSDM1CLKSOURCE_D2PCLK1;
  PeriphClkInitStruct.Usart16ClockSelection = RCC_USART16910CLKSOURCE_D2PCLK2;
  PeriphClkInitStruct.I2c1235ClockSelection = RCC_I2C1235CLKSOURCE_D2PCLK1;
  PeriphClkInitStruct.UsbClockSelection = RCC_USBCLKSOURCE_PLL3;
  PeriphClkInitStruct.AdcClockSelection = RCC_ADCCLKSOURCE_PLL2;
  if (HAL_RCCEx_PeriphCLKConfig(&PeriphClkInitStruct) != HAL_OK)
  {
    Error_Handler();
  }
  /** Enable USB Voltage detector
  */
  HAL_PWREx_EnableUSBVoltageDetector();
}

int main(void)
{
	int16_t enc;
    int8_t i;
    uint32_t act, tot;

    /* Enable the CPU Cache */
    CPU_CACHE_Enable();

	/* init systick handler before letting HAL start it */
	systick_init();

    /* STM32H7xx HAL library initialization:
       - Systick timer is configured by default as source of time base, but user
         can eventually implement his proper time base source (a general purpose
         timer for example or other time source), keeping in mind that Time base
         duration should be kept 1ms since PPP_TIMEOUT_VALUEs are defined and
         handled in milliseconds basis.
       - Set NVIC Group Priority to 4
       - Low Level Initialization
     */
    HAL_Init();

    /* Configure the system clock to 550 MHz */
    SystemClock_Config();

    /* start cyclesleep */
	cyccnt_enable();

	/* init the UART for diagnostics */
	setup_usart();
	init_printf(0,usart_putc);
	printf("\n\n\rH730 Audio Main\n\r");
	printf("CPUID: 0x%08X\n\r", SCB->CPUID);
	printf("IDCODE: 0x%08X\n\r", DBGMCU->IDCODE);
	printf("Version: %s\n\r", fwVersionStr);
	printf("Build Date: %s\n\r", bdate);
	printf("Build Time: %s\n\r", btime);
	printf("\n");
	printf("SYSCLK = %d\n\r", HAL_RCC_GetSysClockFreq());
	printf("\n");

	/* initialize LEDs */
	LEDInit();
	printf("LED initialized\n\r");

	/* initialize the Quad SPI RAM */
	qspi_init();
	printf("QSPI initialized\n\r");

#if 1
	if(qspi_test())
		printf("QSPI Test Failed\n\r");
	else
		printf("QSPI Test Passed\n\r");
#endif

	/* initialize the SD card power control */
	sdio_init();
	printf("SD Card slot initialized\n\r");

#if 1
	/* Check if SD card works */
	if(sdio_detect())
	{
		printf("SD Card Present\n\r");
		sdio_power(1);
		sdio_test();
		sdio_power(0);
	}
	else
		printf("No SD Card\n\r");
#endif

    /* initialize I2C bus processing */
    shared_i2c_init();
    printf("I2C initialized\n\r");

    /* initialize eeprom */
    eeprom_init();
    printf("EEPROM initialized\n\r");

/* initialize the spi port and LCD */
	gfx_init(&ST7789_drvr);
	gfx_clrscreen();
	gfx_drawstr(0, 0, "Hello World!");
	gfx_set_forecolor(GFX_RED);
	gfx_fillcircle(40, 60, 30);
	gfx_set_forecolor(GFX_GREEN);
	gfx_fillcircle(70, 90, 30);
	gfx_set_forecolor(GFX_BLUE);
	gfx_fillcircle(100, 120, 30);
	ST7789_backlight(1);
	printf("GFX initialized\n\r");

    /* initialize audio processing */
	ADC_Init(GPIO_PIN_0|GPIO_PIN_1|GPIO_PIN_2|GPIO_PIN_3|GPIO_PIN_4|GPIO_PIN_5|GPIO_PIN_6|GPIO_PIN_7);
	printf("ADC initialized\n\r");

    /* initialize audio processing */
	Audio_Init();
	printf("Audio initialized\n\r");

	/* setup codec */
	Codec_Init();
	printf("Codec initialized\n\r");

	/* init Codec */
	if(Codec_Reset()==0)
		printf("Codec reset\n\r");
	else
		printf("Codec did not reset properly\n\r");

	/* initialize SAI port */
	sai_init(FAST_DMA_BUFFSZ);
	printf("SAI initialized\n\r");
	printf("SAI Sample Rate = %d \n\r", sai_get_samplerate());
    printf("SAI Buffer size = %d \n\r", sai_get_bufsz());

	/* unmute */
	Codec_Mute(0);
	printf("Codec unmuted\n\r");

    /* Infinite loop */
	printf("Looping...\n\r");
	while(1)
	{
        /* Audio load */
        get_meas(&act, &tot);
        printf("%2d %% ", 100*act/tot);

        /* Dump ADC and button state */
        for(i=0;i<ADC_NUMCHLS;i++)
        {
            printf("%03X ", ADC_getraw(i));
        }

		enc += systick_get_enc();
		printf("%1d %d  \r", systick_get_button(ENC_E), enc);

		LEDToggle(0);
		HAL_Delay(100);
	}

	/* should never get here */
	return 0;
}

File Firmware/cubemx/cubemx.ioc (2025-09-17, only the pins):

Mcu.UserName=STM32H730VBTx
PA0.Signal=ADC1_INP16
PA1.Signal=ADC1_INP17
PA11.Signal=USB_OTG_HS_DM
PA12.Signal=USB_OTG_HS_DP
PA13(JTMS/SWDIO).Signal=DEBUG_JTMS-SWDIO
PA14(JTCK/SWCLK).Signal=DEBUG_JTCK-SWCLK
PA2.Signal=ADCx_INP14
PA3.Signal=ADCx_INP15
PA4.Signal=ADCx_INP18
PA5.Signal=ADCx_INP19
PA6.Signal=ADCx_INP3
PA7.Signal=ADCx_INP7
PA9.Signal=SPI2_SCK
PB10.Signal=I2C2_SCL
PB11.Signal=I2C2_SDA
PB13.Signal=OCTOSPIM_P1_IO2
PB14.Signal=SPI2_MISO
PB15.Signal=SPI2_MOSI
PB2.Signal=OCTOSPIM_P1_CLK
PB3(JTDO/TRACESWO).Signal=DEBUG_JTDO-SWO
PB6.Signal=USART1_TX
PB7.Signal=USART1_RX
PB8.Signal=I2C1_SCL
PB9.Signal=I2C1_SDA
PC10.Signal=SDMMC1_D2
PC11.Signal=SDMMC1_D3
PC12.Signal=SDMMC1_CK
PC5.Signal=ADCx_INP8
PC8.Signal=SDMMC1_D0
PC9.Signal=SDMMC1_D1
PD11.Signal=OCTOSPIM_P1_IO0
PD12.Signal=OCTOSPIM_P1_IO1
PD13.Signal=OCTOSPIM_P1_IO3
PD2.Signal=SDMMC1_CMD
PD3.Signal=S_CKOUTDFSDM1
PD6.Signal=S_DATAIN1DFSDM1
PD7.Signal=S_CKIN1DFSDM1
PE11.Signal=OCTOSPIM_P1_NCS
PE2.Signal=SAI1_MCLK_A
PE3.Signal=SAI1_SD_B
PE4.Signal=SAI1_FS_A
PE5.Signal=SAI1_SCK_A
PE6.Signal=SAI1_SD_A
PH0-OSC_IN.Signal=RCC_OSC_IN
PH1-OSC_OUT.Signal=RCC_OSC_OUT

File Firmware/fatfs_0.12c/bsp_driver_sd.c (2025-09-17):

/**
 ******************************************************************************
  * @file    bsp_driver_sd.c for H7 (based on stm32h743i_eval_sd.c)
  * @brief   This file includes a generic uSD card driver.
  ******************************************************************************
  * @attention
  *
  * <h2><center>&copy; Copyright (c) 2019 STMicroelectronics.
  * All rights reserved.</center></h2>
  *
  * This software component is licensed by ST under Ultimate Liberty license
  * SLA0044, the "License"; You may not use this file except in compliance with
  * the License. You may obtain a copy of the License at:
  *                             www.st.com/SLA0044
  *
  ******************************************************************************
  */

/* USER CODE BEGIN FirstSection */
/* can be used to modify / undefine following code or add new definitions */
/* USER CODE END FirstSection */
/* Includes ------------------------------------------------------------------*/
#include "bsp_driver_sd.h"
#include "printf.h"
#include "sdio.h"

/* Extern variables ---------------------------------------------------------*/
extern SD_HandleTypeDef hsd1;

/* variables ---------------------------------------------------------*/
static volatile  uint32_t  WriteStatus = 0, ReadStatus = 0;

/* USER CODE BEGIN BeforeInitSection */
/* can be used to modify / undefine following code or add code */
/* USER CODE END BeforeInitSection */
/**
  * @brief  Initializes the SD card device.
  * @retval SD status
  */
uint8_t BSP_SD_Init(void)
{
  uint8_t sd_state = MSD_OK;
  /* Check if the SD card is plugged in the slot */
  if (BSP_SD_IsDetected() != SD_PRESENT)
  {
	//printf("BSP_SD_Init: card not detected (SHOULDN'T HAPPEN)\n\r");
    return MSD_ERROR_SD_NOT_PRESENT;
  }

  //printf("BSP_SD_Init: &hsd1 = 0x%08X\n\r", &hsd1);

  /* HAL SD initialization */
  sd_state = HAL_SD_Init(&hsd1);
  /* Configure SD Bus width (4 bits mode selected) */
  if (sd_state == MSD_OK)
  {
	printf("BSP_SD_Init: HAL_SD_Init OK\n\r");
#if 0
	  /* NOT NEEDED - HAL_SD_Init() does this already */
	/* Enable wide operation */
    if (HAL_SD_ConfigWideBusOperation(&hsd1, SDMMC_BUS_WIDE_4B) != HAL_OK)
    {
	  printf("BSP_SD_Init: HAL_SD_ConfigWideBusOperation Failed\n\r");
      sd_state = MSD_ERROR;
    }
	else
	  printf("BSP_SD_Init: HAL_SD_ConfigWideBusOperation OK\n\r");
#endif

    /* enable IRQs for SDMMC  - priority lower than audio (which is 1) */
    HAL_NVIC_SetPriority(SDMMC1_IRQn, 2, 0);
    HAL_NVIC_EnableIRQ(SDMMC1_IRQn);
  }
  else
  {
	  printf("BSP_SD_Init: HAL_SD_Init failed with result %d\n\r", sd_state);
  }

  return sd_state;
}
/* USER CODE BEGIN AfterInitSection */
/* can be used to modify previous code / undefine following code / add code */
/* USER CODE END AfterInitSection */

/**
  * @brief  Configures Interrupt mode for SD detection pin.
  * @retval Returns 0 in success otherwise 1.
  */
uint8_t BSP_SD_ITConfig(void)
{
  /* TBI: add user code here depending on the hardware configuration used */

  return (uint8_t)0;
}

/* USER CODE BEGIN BeforeReadBlocksSection */
/* can be used to modify previous code / undefine following code / add code */
/* USER CODE END BeforeReadBlocksSection */
/**
  * @brief  Reads block(s) from a specified address in an SD card, in polling mode.
  * @param  pData: Pointer to the buffer that will contain the data to transmit
  * @param  ReadAddr: Address from where data is to be read
  * @param  NumOfBlocks: Number of SD blocks to read
  * @param  Timeout: Timeout for read operation
  * @retval SD status
  */
uint8_t BSP_SD_ReadBlocks(uint32_t *pData, uint32_t ReadAddr, uint32_t NumOfBlocks, uint32_t Timeout)
{
  uint8_t sd_state = MSD_OK;

  if (HAL_SD_ReadBlocks(&hsd1, (uint8_t *)pData, ReadAddr, NumOfBlocks, Timeout) != HAL_OK)
  {
      printf("BSP_SD_ReadBlocks: fail, err = %d\n\r", hsd1.ErrorCode);
      //printf("\t pData = 0x%08X, ReadAddr = 0x%08X, NumOfBlocks = %d\n\r", pData, ReadAddr, NumOfBlocks);
      sd_state = MSD_ERROR;
  }
  else
  {
	  //printf("BSP_SD_ReadBlocks: HAL_SD_ReadBlocks OK\n\r");
  }

  return sd_state;
}

/* USER CODE BEGIN BeforeWriteBlocksSection */
/* can be used to modify previous code / undefine following code / add code */
/* USER CODE END BeforeWriteBlocksSection */
/**
  * @brief  Writes block(s) to a specified address in an SD card, in polling mode.
  * @param  pData: Pointer to the buffer that will contain the data to transmit
  * @param  WriteAddr: Address from where data is to be written
  * @param  NumOfBlocks: Number of SD blocks to write
  * @param  Timeout: Timeout for write operation
  * @retval SD status
  */
uint8_t BSP_SD_WriteBlocks(uint32_t *pData, uint32_t WriteAddr, uint32_t NumOfBlocks, uint32_t Timeout)
{
  uint8_t sd_state = MSD_OK;

  if (HAL_SD_WriteBlocks(&hsd1, (uint8_t *)pData, WriteAddr, NumOfBlocks, Timeout) != HAL_OK)
  {
    printf("BSP_SD_WriteBlocks: fail, err = %d\n\r", hsd1.ErrorCode);
    //printf("\t pData = 0x%08X, WriteAddr = 0x%08X, NumOfBlocks = %d\n\r", pData, WriteAddr, NumOfBlocks);
    sd_state = MSD_ERROR;
  }

  return sd_state;
}

/* USER CODE BEGIN BeforeReadDMABlocksSection */
/* can be used to modify previous code / undefine following code / add code */
/* USER CODE END BeforeReadDMABlocksSection */
/**
  * @brief  Reads block(s) from a specified address in an SD card, in DMA mode.
  * @param  pData: Pointer to the buffer that will contain the data to transmit
  * @param  ReadAddr: Address from where data is to be read
  * @param  NumOfBlocks: Number of SD blocks to read
  * @retval SD status
  */
uint8_t BSP_SD_ReadBlocks_DMA(uint32_t *pData, uint32_t ReadAddr, uint32_t NumOfBlocks)
{
  uint8_t sd_state = MSD_OK;
  uint32_t timeout;
  uint32_t alignedAddr;

  ReadStatus = 0;

  /* Read block(s) in DMA transfer mode */
  if (HAL_SD_ReadBlocks_DMA(&hsd1, (uint8_t *)pData, ReadAddr, NumOfBlocks) != HAL_OK)
  {
    sd_state = MSD_ERROR;
  }
  else
  {
      /* Wait that the reading process is completed or a timeout occurs */
      timeout = HAL_GetTick();
      while((ReadStatus == 0) && ((HAL_GetTick() - timeout) < BSP_SD_TIMEOUT))
      {
      }

      /* incase of a timeout return error */
      if (ReadStatus == 0)
      {
        sd_state = MSD_ERROR;
      }
      else
      {
        ReadStatus = 0;
        timeout = HAL_GetTick();

        while((HAL_GetTick() - timeout) < BSP_SD_TIMEOUT)
        {
          if (BSP_SD_GetCardState() == SD_TRANSFER_OK)
          {
            sd_state = MSD_OK;
              /*
                 the SCB_InvalidateDCache_by_Addr() requires a 32-Byte aligned address,
                 adjust the address and the D-Cache size to invalidate accordingly.
               */
              alignedAddr = (uint32_t)pData & ~0x1F;
              SCB_InvalidateDCache_by_Addr((uint32_t*)pData, NumOfBlocks*512 + ((uint32_t)pData - alignedAddr));
             break;
          }
        }
      }
  }

  return sd_state;
}
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

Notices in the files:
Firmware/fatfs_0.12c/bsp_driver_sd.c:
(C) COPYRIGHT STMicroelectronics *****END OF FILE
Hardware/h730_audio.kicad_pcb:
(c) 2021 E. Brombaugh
